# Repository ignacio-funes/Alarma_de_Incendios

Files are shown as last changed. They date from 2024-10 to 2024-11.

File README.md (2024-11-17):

# Alarma de Incendios
## Introducción
Mi proyecto consistirá en armar un sistema de alarma de incendios, que sea suficientemente confiable para ser utilizado en un ambiente de trabajo. Esto requerirá una serie de funciones que aprovecharán las posibilidades del ESP-32.

## Objetivos
1. Responder a fuegos sin demoras significativas.
   
2. Alertar, de formas visibles, a las personas en riesgo.
   
3. Permitir acceso rápido al estado del sistema a través de la red.
   
## Alcances
- Mantener y actualizar una página web. Para acceder, hay que conectarse a la red del módulo ESP32.

- Monitorear el estado de una sola habitación.

- Alimentado con una batería de 9V, tendrá una autonomía limitada.

## Funcionalidad
El sistema tomará en cuenta las lecturas tanto de un sensor infrarrojo como de un detector de humo para su lógica. En caso de activarse cualquiera de los sensores, el sistema activará su estado de alarma. Se encenderán el buzzer y el led rojo, y se enviarán alertas a la red. De lo contrario, se encenderá el led verde, y se enviarán actualizaciones a la red en intervalos regulares.

## Propuestas a futuro
El sistema podría ser adaptado para controlar múltiples sistemas, distintas oficinas en un edificio, por ejemplo. Sería posible, entonces, monitorear el estado de cada una, y en caso de incendio, controlar el avance del fuego. Esto se podría combinar con otras aplicaciones, como sistemas de vigilancia o control de ambiente, tanto para la mejor prevención de accidentes como para un espacio de trabajo más cómodo y saludable. 

## Más información
En las carpetas del repositorio se encuentra más información del proyecto, y los archivos necesarios para hacerlo funcionar.

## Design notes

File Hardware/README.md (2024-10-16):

# Hardware
En esta sección encontramos la información relacionada con el hardware del proyecto; su lista de componentes, datasheets, esquemáticos, modelos de PCB, etc.

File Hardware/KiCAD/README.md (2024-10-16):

# KiCAD
En esta carpeta se cargarán los cambios en el diseño de el sistema, tanto en su esquemático como en su PCB.

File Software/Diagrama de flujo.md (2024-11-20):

```mermaid
graph TD
    A[Start] --> B[Initialize NVS Flash]
    B --> C[Initialize WiFi in SoftAP mode]
    C --> D[Initialize GPIO pins<br/>LEDs and Buzzer]
    D --> E[Initialize ADC<br/>for Gas and IR sensors]
    
    E --> F[Start Web Server]
    E --> G[Create Sensor Check Task]
    
    G --> H[Sensor Check Loop]
    H --> I[Read Gas Sensor<br/>10 samples average]
    I --> J[Read IR Sensor<br/>10 samples average]
    
    J --> K{Gas > Threshold OR<br/>IR < Threshold?}
    K -->|Yes| L[Set Alarm State ON<br/>Red LED + Buzzer ON<br/>Green LED OFF]
    K -->|No| M[Set Alarm State OFF<br/>Red LED + Buzzer OFF<br/>Green LED ON]
    
    L --> N[Wait 500ms]
    M --> N
    N --> H
    
    F --> O[Web Server Running]
    O --> P[Root Handler</br>/]
    O --> Q[Status Handler</br>/status]
    
    P --> R[Serve HTML Page]
    Q --> S[Return Sensor Values<br/>and Alarm State]
    
    style A fill:##b3a,stroke:#333,stroke-width:2px
    style O fill:#b3a,stroke:#333,stroke-width:2px
    style H fill:#b3a,stroke:#333,stroke-width:2px
    style K fill:#b3a,stroke:#333,stroke-width:2px
```

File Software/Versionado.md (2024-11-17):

# Versionado

 + KiCAD 8.0
 + Espidf 1.8.1

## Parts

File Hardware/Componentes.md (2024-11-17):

# Componentes utilizados

+ Un módulo receptor infrarrojo con salida analógica y salida digital regulable.
  Detectará emisiones de luz en el espectro infrarrojo, y está construido para ser
  sensible a las emitidas por las llamas.

+ Un buzzer. Alertará al usuario en caso de incendio.

+ Dos LEDs de distintos colores, preferiblemente rojo y verde. Junto con el buzzer, permiten
  conocer el estado de alerta.

+ Módulo detector de humo, con un sensor MQ-2 integrado. Detecta GLP, propano, 
  metano, alcohol, hidrógeno y humo; siendo más sensible a los dos primeros y al hidrógeno.

+ Módulo ESP-32 con capacidad para comunicación inalámbrica con WIFI y 5 pines GPIO. Yo utilizo
  el kit ESP32 DEVKIT V1.

+ Logic Level Shifter de cuatro canales, necesario para permitir la comunicación entre los
  pines GPIO del ESP y los sensores.

+ Regulador de tensión LM7805, con salida de 5V.

+ Regulador de tensión ajustable LM317, con salida de 3,3V.

+ Resistencias de:
  - 1 kOhm
  - 1,64 kOhm
  - 100 Ohm
  - 115 Ohm

+ Capacitores:
  - 0,22 uF, polarizado
  - 0,1 uF, cerámico

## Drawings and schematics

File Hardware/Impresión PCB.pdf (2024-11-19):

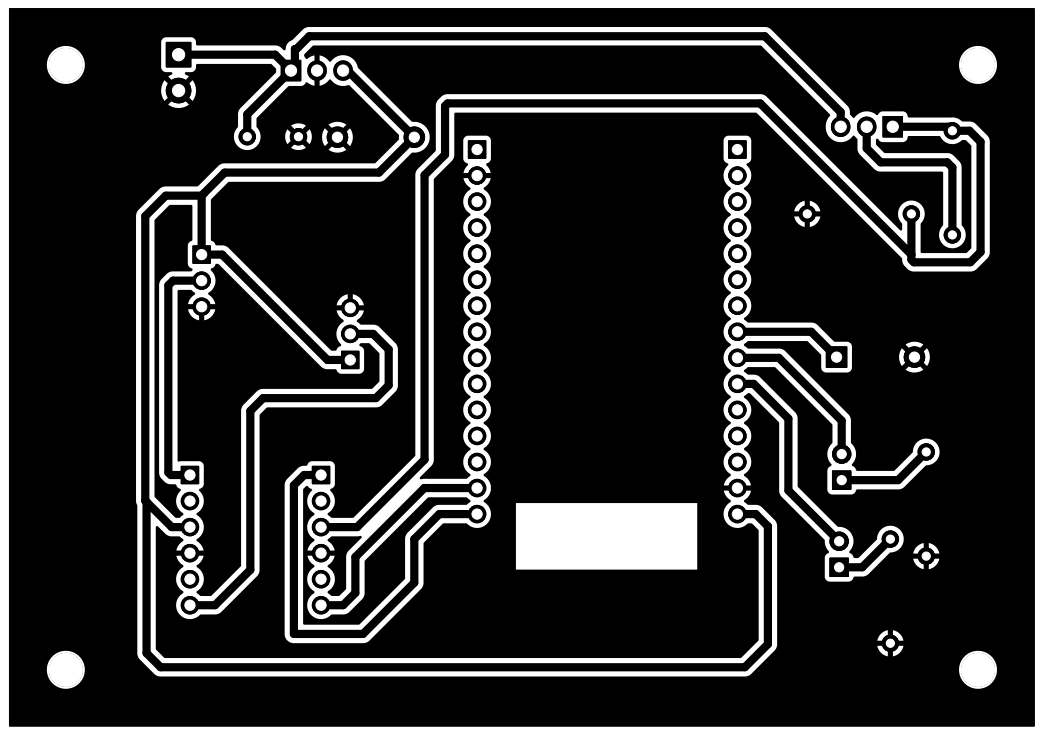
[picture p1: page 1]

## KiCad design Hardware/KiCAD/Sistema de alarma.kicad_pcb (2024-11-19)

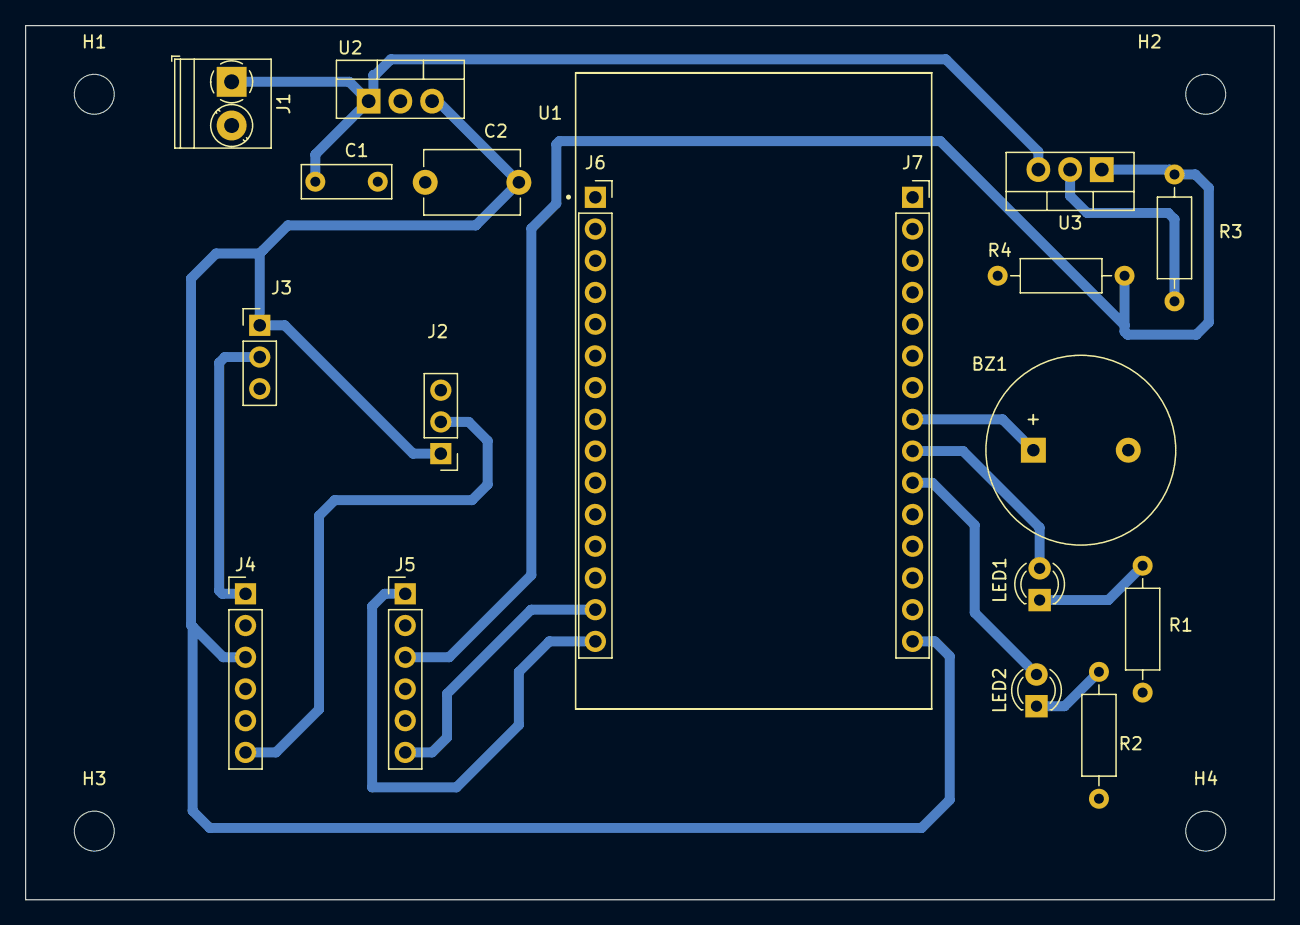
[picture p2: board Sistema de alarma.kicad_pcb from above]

Board: 2 copper layers, 100.0 x 70.0 mm, 23 parts (0 on the bottom side), 14 nets.

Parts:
BZ1: Buzzer; Buzzer_15x7.5RM7.6
C1: 0,22uF; C_Disc_D7.0mm_W2.5mm_P5.00mm
C2: 0,1uF, ceramic disc; C_Disc_D7.5mm_W5.0mm_P7.50mm
H1, H2, H3, H4: MountingHole; MountingHole_3.2mm_M3
J1: Alimentación; TerminalBlock_Phoenix_PT-1,5-2-3.5-H_1x02_P3.50mm_Horizontal
J2: MQ2 Conn; PinHeader_1x03_P2.54mm_Vertical
J3: IR R Pins; PinHeader_1x03_P2.54mm_Vertical
J4, J5: Conn_01x06_Socket; PinHeader_1x06_P2.54mm_Vertical
J6, J7: Conn_01x15_Socket; PinSocket_1x15_P2.54mm_Vertical
LED1: Rojo; LED_D3.0mm
LED2: Verde; LED_D3.0mm
R1: 115; R_Axial_DIN0207_L6.3mm_D2.5mm_P10.16mm_Horizontal
R2: 100; R_Axial_DIN0207_L6.3mm_D2.5mm_P10.16mm_Horizontal
R3: 1k; R_Axial_DIN0207_L6.3mm_D2.5mm_P10.16mm_Horizontal
R4: 1,64k; R_Axial_DIN0207_L6.3mm_D2.5mm_P10.16mm_Horizontal
U1: ESP32-DEVKIT-V1; MODULE_ESP32_DEVKIT_V1
U2: LM7805_TO220; TO-220-3_Vertical
U3: LM317_TO-220; TO-220-3_Vertical

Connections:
3,3V: J5.3, R3.2, R4.1, U3.1 (ADJ)
5V: C2.1, J2.1, J3.1, J4.3, J7.15, U2.3 (VO)
+9V: C1.1, J1.1, U2.1 (VI), U3.3 (VI)
/LED1 K: LED1.1 (K), R1.1
/LED2 K: LED2.1 (K), R2.1
/LM317 Vo: R3.1, U3.2 (VO)
Buzzer: BZ1.1 (-), J7.8
Earth: BZ1.2 (+), C1.2, C2.2, J1.2, J2.3, J3.3, J4.4, J5.4, J6.2, J7.14, R1.2, R2.2, R4.2, U2.2 (GND)
IR In: J5.1, J6.15
IR Signal: J3.2, J4.1
LED1: J7.9, LED1.2 (A)
LED2: J7.10, LED2.2 (A)
MQ2 In: J5.6, J6.14
MQ2 Signal: J2.2, J4.6

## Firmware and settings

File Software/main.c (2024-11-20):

/*  WiFi softAP Example

   This example code is in the Public Domain (or CC0 licensed, at your option.)

   Unless required by applicable law or agreed to in writing, this
   software is distributed on an "AS IS" BASIS, WITHOUT WARRANTIES OR
   CONDITIONS OF ANY KIND, either express or implied.
*/
#include <string.h>
#include "freertos/FreeRTOS.h"
#include "freertos/task.h"
#include "esp_mac.h"
#include "esp_wifi.h"
#include "esp_event.h"
#include "esp_log.h"
#include "nvs_flash.h"
#include "driver/adc.h"
#include "driver/gpio.h"
#include "esp_http_server.h"
#include "esp_mac.h"
#include "esp_adc/adc_oneshot.h"
#include "esp_adc/adc_cali.h"
#include "esp_adc/adc_cali_scheme.h"

#include "lwip/err.h"
#include "lwip/sys.h"



#define EXAMPLE_ESP_WIFI_SSID      "yourAP"
#define EXAMPLE_ESP_WIFI_PASS      "yourPassword"
#define EXAMPLE_ESP_WIFI_CHANNEL   CONFIG_ESP_WIFI_CHANNEL
#define EXAMPLE_MAX_STA_CONN       CONFIG_ESP_MAX_STA_CONN

#define GAS_SENSOR_ADC_UNIT    ADC_UNIT_1
#define GAS_SENSOR_ADC_CHANNEL ADC_CHANNEL_6    // GPIO34
#define IR_SENSOR_ADC_CHANNEL  ADC_CHANNEL_7    // GPIO35
#define ADC_ATTEN             ADC_ATTEN_DB_11
#define ADC_BITWIDTH          ADC_BITWIDTH_12

#define RED_LED_GPIO               GPIO_NUM_32
#define GREEN_LED_GPIO             GPIO_NUM_33
#define BUZZER_GPIO               GPIO_NUM_5

#define GAS_THRESHOLD             300
#define IR_THRESHOLD              3900
#define SENSOR_CHECK_INTERVAL_MS  500



static adc_oneshot_unit_handle_t adc1_handle;
static adc_cali_handle_t adc1_cali_handle = NULL;

static bool alarm_state = false;
static bool do_calibration;

static const char *TAG = "wifi softAP";



static void init_gpio(void);
static bool init_adc(void);
static void update_outputs(bool green_state);
static int get_adc_reading_average(int channel);
static void check_sensors_task(void *pvParameters);
static httpd_handle_t start_webserver(void);



static void init_gpio(void)
{
    gpio_config_t io_conf = {
        .pin_bit_mask = (1ULL << RED_LED_GPIO) | (1ULL << GREEN_LED_GPIO) | (1ULL << BUZZER_GPIO),
        .mode = GPIO_MODE_OUTPUT,
        .pull_up_en = GPIO_PULLUP_DISABLE,
        .pull_down_en = GPIO_PULLDOWN_DISABLE,
        .intr_type = GPIO_INTR_DISABLE
    };
    gpio_config(&io_conf);
    update_outputs(false);  
}

static bool init_adc(void)
{
    esp_err_t ret;
    bool cali_enable = false;

    // ADC1 Init
    adc_oneshot_unit_init_cfg_t init_config1 = {
        .unit_id = ADC_UNIT_1,
    };
    ESP_ERROR_CHECK(adc_oneshot_new_unit(&init_config1, &adc1_handle));

    // ADC1 Config
    adc_oneshot_chan_cfg_t config = {
        .atten = ADC_ATTEN,
        .bitwidth = ADC_BITWIDTH,
    };
    ESP_ERROR_CHECK(adc_oneshot_config_channel(adc1_handle, GAS_SENSOR_ADC_CHANNEL, &config));
    ESP_ERROR_CHECK(adc_oneshot_config_channel(adc1_handle, IR_SENSOR_ADC_CHANNEL, &config));

    // Calibration Init
    #if ADC_CALI_SCHEME_CURVE_FITTING_SUPPORTED
    adc_cali_curve_fitting_config_t cali_config = {
        .unit_id = ADC_UNIT_1, 
        .atten = ADC_ATTEN,
        .bitwidth = ADC_BITWIDTH,
    };
    ret = adc_cali_create_scheme_curve_fitting(&cali_config, &adc1_cali_handle);
    if (ret == ESP_OK) {
        cali_enable = true;
    }
    #endif

    do_calibration = cali_enable;
    return true;
}

static void update_outputs(bool green_state)
{
    gpio_set_level(GREEN_LED_GPIO, green_state);
    gpio_set_level(RED_LED_GPIO, !green_state);
    gpio_set_level(BUZZER_GPIO, !green_state);
}

static int get_adc_reading_average(int channel)
{
    const int samples = 10;
    int sum = 0;
    int voltage;
    
    for (int i = 0; i < samples; i++) {
        int raw;
        ESP_ERROR_CHECK(adc_oneshot_read(adc1_handle, channel, &raw));
        
        if (do_calibration) {
            ESP_ERROR_CHECK(adc_cali_raw_to_voltage(adc1_cali_handle, raw, &voltage));
            sum += voltage;
        } else {
            sum += raw;
        }
        vTaskDelay(pdMS_TO_TICKS(2));
    }
    
    return sum / samples;
}

static void check_sensors_task(void *pvParameters)
{
    TickType_t last_wake_time = xTaskGetTickCount();
    
    while (1) {
        int gas_value = get_adc_reading_average(GAS_SENSOR_ADC_CHANNEL);
        int ir_value = get_adc_reading_average(IR_SENSOR_ADC_CHANNEL);
        
        // If using calibrated values, adjust thresholds accordingly
        if (do_calibration) {
            alarm_state = (gas_value >= GAS_THRESHOLD * 3.3 / 4095) || 
                         (ir_value <= IR_THRESHOLD * 3.3 / 4095);
        } else {
            alarm_state = (gas_value >= GAS_THRESHOLD) || (ir_value <= IR_THRESHOLD);
        }
        
        update_outputs(!alarm_state);
        
        ESP_LOGI(TAG, "Gas: %d, IR: %d, Alarm: %d", gas_value, ir_value, alarm_state);
        vTaskDelayUntil(&last_wake_time, pdMS_TO_TICKS(SENSOR_CHECK_INTERVAL_MS));
    }
}

static esp_err_t status_handler(httpd_req_t *req)
{
    char resp[32];
    int gas_value = get_adc_reading_average(GAS_SENSOR_ADC_CHANNEL);
    int ir_value = get_adc_reading_average(IR_SENSOR_ADC_CHANNEL);
    
    // If calibrated, convert to mV for display
    if (do_calibration) {
        snprintf(resp, sizeof(resp), "%d,%d,%d\n", 
                gas_value, 
                ir_value,  
                alarm_state ? 1 : 0);
    } else {
        snprintf(resp, sizeof(resp), "%d,%d,%d\n", 
                gas_value,
                ir_value,
                alarm_state ? 1 : 0);
    }
    
    httpd_resp_set_type(req, "text/plain");
    httpd_resp_set_hdr(req, "Access-Control-Allow-Origin", "*");
    return httpd_resp_send(req, resp, strlen(resp));
}

static esp_err_t root_handler(httpd_req_t *req)
{
    const char* html = get_html_content(); 
    httpd_resp_set_type(req, "text/html");
    return httpd_resp_send(req, html, strlen(html));
}

static httpd_handle_t start_webserver(void)
{
    httpd_config_t config = HTTPD_DEFAULT_CONFIG();
    httpd_handle_t server = NULL;

    httpd_uri_t root = {
        .uri       = "/",
        .method    = HTTP_GET,
        .handler   = root_handler,
        .user_ctx  = NULL
    };

    httpd_uri_t status = {
        .uri       = "/status",
        .method    = HTTP_GET,
        .handler   = status_handler,
        .user_ctx  = NULL
    };

    if (httpd_start(&server, &config) == ESP_OK) {
        httpd_register_uri_handler(server, &root);
        httpd_register_uri_handler(server, &status);
        return server;
    }
    return NULL;
}


static void wifi_event_handler(void* arg, esp_event_base_t event_base,
                                    int32_t event_id, void* event_data)
{
    if (event_id == WIFI_EVENT_AP_STACONNECTED) {
        wifi_event_ap_staconnected_t* event = (wifi_event_ap_staconnected_t*) event_data;
        ESP_LOGI(TAG, "station "MACSTR" join, AID=%d",
                 MAC2STR(event->mac), event->aid);
    } else if (event_id == WIFI_EVENT_AP_STADISCONNECTED) {
        wifi_event_ap_stadisconnected_t* event = (wifi_event_ap_stadisconnected_t*) event_data;
        ESP_LOGI(TAG, "station "MACSTR" leave, AID=%d, reason=%d",
                 MAC2STR(event->mac), event->aid, event->reason);
    }
}

void wifi_init_softap(void)
{
    ESP_ERROR_CHECK(esp_netif_init());
    ESP_ERROR_CHECK(esp_event_loop_create_default());
    esp_netif_create_default_wifi_ap();

    wifi_init_config_t cfg = WIFI_INIT_CONFIG_DEFAULT();
    ESP_ERROR_CHECK(esp_wifi_init(&cfg));

    ESP_ERROR_CHECK(esp_event_handler_instance_register(WIFI_EVENT,
                                                        ESP_EVENT_ANY_ID,
                                                        &wifi_event_handler,
                                                        NULL,
                                                        NULL));

    wifi_config_t wifi_config = {
        .ap = {
            .ssid = EXAMPLE_ESP_WIFI_SSID,
            .ssid_len = strlen(EXAMPLE_ESP_WIFI_SSID),
            .channel = EXAMPLE_ESP_WIFI_CHANNEL,
            .password = EXAMPLE_ESP_WIFI_PASS,
            .max_connection = EXAMPLE_MAX_STA_CONN,
#ifdef CONFIG_ESP_WIFI_SOFTAP_SAE_SUPPORT
            .authmode = WIFI_AUTH_WPA3_PSK,
            .sae_pwe_h2e = WPA3_SAE_PWE_BOTH,
#else /* CONFIG_ESP_WIFI_SOFTAP_SAE_SUPPORT */
            .authmode = WIFI_AUTH_WPA2_PSK,
#endif
            .pmf_cfg = {
                    .required = true,
            },
        },
    };
    if (strlen(EXAMPLE_ESP_WIFI_PASS) == 0) {
        wifi_config.ap.authmode = WIFI_AUTH_OPEN;
    }

    ESP_ERROR_CHECK(esp_wifi_set_mode(WIFI_MODE_AP));
    ESP_ERROR_CHECK(esp_wifi_set_config(WIFI_IF_AP, &wifi_config));
    ESP_ERROR_CHECK(esp_wifi_start());

    ESP_LOGI(TAG, "wifi_init_softap finished. SSID:%s password:%s channel:%d",
             EXAMPLE_ESP_WIFI_SSID, EXAMPLE_ESP_WIFI_PASS, EXAMPLE_ESP_WIFI_CHANNEL);
    httpd_handle_t server = start_webserver();
        if (server == NULL) {
         ESP_LOGE(TAG, "Failed to start web server!");
    }
}



static const char* get_html_content(void)
{
    return "<!DOCTYPE html><html>"
           "<head><title>Alarm Monitor</title>"
           "<meta name='viewport' content='width=device-width, initial-scale=1'>"
           "<style>"
           "body { font-family: Arial, sans-serif; margin: 20px; text-align: center; }"
           ".sensor-card { background-color: #f0f0f0; padding: 20px; margin: 10px; border-radius: 8px; }"
           ".alarm-text { font-size: 24px; font-weight: bold; margin: 20px; padding: 10px; border-radius: 4px; }"
           ".alarm-active { background-color: #ffebee; color: #d32f2f; }"
           ".alarm-inactive { background-color: #e8f5e9; color: #2e7d32; }"
           "</style>"
           "<script>"
           "function updateValues() {"
           "  fetch('/status')"
           "    .then(response => response.text())"
           "    .then(data => {"
           "      const values = data.split(',');"
           "      document.getElementById('sensorGas').innerHTML = values[0];"
           "      document.getElementById('sensorIR').innerHTML = values[1];"
           "      const alarmState = values[2];"
           "      const alarmText = document.getElementById('alarmText');"
           "      if(alarmState.trim() === '1') {"
           "        alarmText.className = 'alarm-text alarm-active';"
           "        alarmText.innerHTML = 'ALARM ON';"
           "      } else {"
           "        alarmText.className = 'alarm-text alarm-inactive';"
           "        alarmText.innerHTML = 'ALARM OFF';"
           "      }"
           "    })"
           "    .catch(error => console.error('Error:', error));"
           "}"
           "updateValues();"
           "setInterval(updateValues, 2000);"
           "</script></head>"
           "<body>"
           "<h1>Alarm Monitor</h1>"
           "<div id='alarmText' class='alarm-text'>Loading alarm state...</div>"
           "<div class='sensor-card'>"
           "<h2>Sensor de Gas</h2>"
           "<p>Value: <span id='sensorGas'>0</span></p>"
           "</div>"
           "<div class='sensor-card'>"
           "<h2>Sensor IR</h2>"
           "<p>Value: <span id='sensorIR'>0</span></p>"
           "</div>"
           "</body></html>";
}



void app_main(void)
{
    esp_err_t ret = nvs_flash_init();
    if (ret == ESP_ERR_NVS_NO_FREE_PAGES || ret == ESP_ERR_NVS_NEW_VERSION_FOUND) {
      ESP_ERROR_CHECK(nvs_flash_erase());
      ret = nvs_flash_init();
    }
    ESP_ERROR_CHECK(ret);

    ESP_LOGI(TAG, "ESP_WIFI_MODE_AP");
    wifi_init_softap();

    init_gpio();
    if (!init_adc()) {
        ESP_LOGE(TAG, "ADC initialization failed");
        return;
    }
    
    xTaskCreate(check_sensors_task, "sensor_check", 4096, NULL, 5, NULL);
}

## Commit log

2024-11-17 Create Diagrama de flujo.md
2024-11-17 Update Diagrama de flujo.md
2024-11-20 Rename Hardware/KiCAD/Impresión PCB.pdf to Hardware/Impresión PCB.pdf
